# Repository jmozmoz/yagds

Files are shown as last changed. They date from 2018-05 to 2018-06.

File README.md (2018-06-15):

# yagds
This project is yet another garage door sensor.

Sensor data of changing door positions are captured by two reed sensors
connected to a ESP-01 module and
forwarded using the MQTT to a MQTT broker. A Python script subscribes to
these MQTT messages and implements a state machine representing the state of
the door (open, closed, moving). If the state of the door changes a Telegram
Bot notifies Telegram clients connected to it.

carrier board schematics

By using Telegram to distribute changes, the MQTT broker does not need to be
accessible from the internet. Also the Android Telegram Bot supports Android
Auto, so the garage door state can easily be sent to your car.

## Hardware

### ESP-01 module

The hardware is based on the ESP-01 module using the microchip
[ESP8266](https://en.wikipedia.org/wiki/ESP8266) microcontroller. This
microchip includes a micro controller with WIFI and TCP/IP capabilities and
can be programmed with the Arduino tool chain. The ESP-01 provides easy
access to 8 of the pins of the microchip of which up to 4 can be used as
general purpose input/output (GPIO): GPIO0, GPIO2, TX(GPIO1), RX(GPIO3)

But the voltage level of some of the GPIO pins are used to select the
[boot mode](https://github.com/esp8266/esp8266-wiki/wiki/Boot-Process#esp-boot-modes)
during power-up/after a reset. The configuration which finally worked for me,
is using GPIO0 and GPIO3 and make sure, that they are at high voltage
level (3.3 V) during reset.

### Carrier Board

The micro controller should go to deep sleep mode after the door reached the
open or closed position. This saves energy if the hardware should be powered
by battery. To wake-up it up again, changes at the reed contacts should
trigger a pulse on the RST pin. Based on the idea described
[here (in German)](http://esp8266-server.de/Reedkontakt.html) for both, GPIO0
and RX, a XOR gate is used to compare the signal with a delayed one. The latter
is produced by RC-circuits. If the signal changes, the delayed signal keeps is
different from the un-delayed signal and the XOR gate outputs one (the two
gates in the top left part of the schematics below). If at least one of
the signals has changed its state, the output of the OR gate is one.
The output of the OR gate is inverted by another XOR gate (top right of the
schematics) and used as input for the RST (reset) pin.

To make sure, that the GPIO pins are at high voltage to boot correctly the
output of the OR gate is delayed by another RC circuit and ORed with the
signals of the GPIO pins. So these pins stay at high until the boot-up
has been completed.

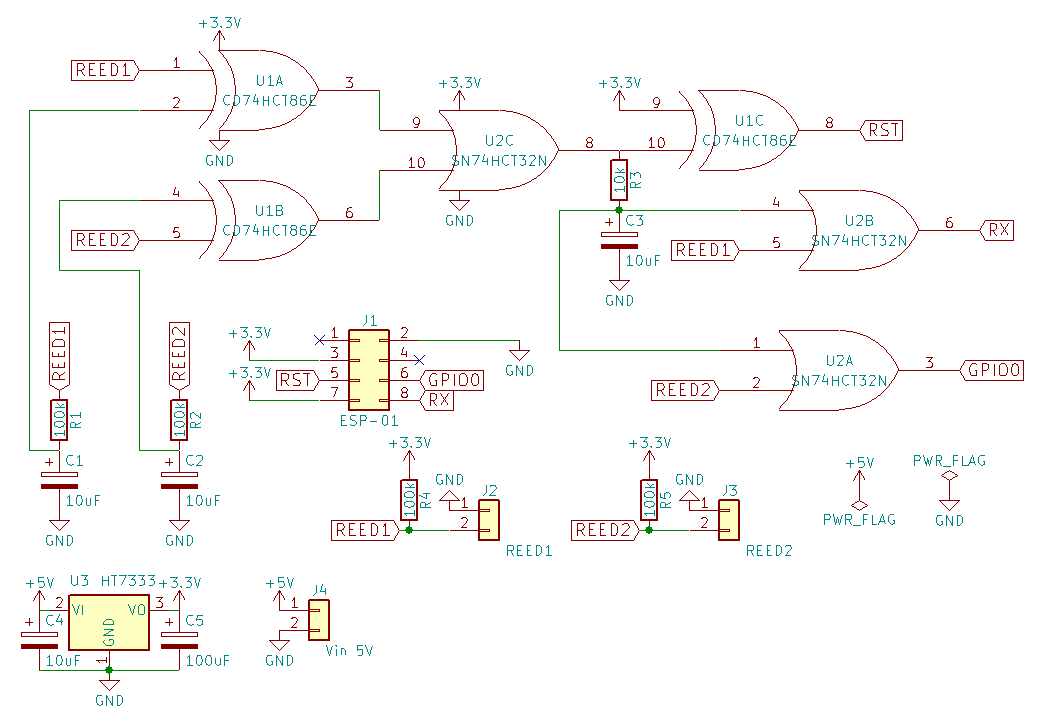
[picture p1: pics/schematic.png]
carrier board schematics


The RC circuits and the OR/XOR gates together with a voltage regulator
for the 3.3 V power supply of the gates and ESP-01 are combined on
a PCB board which carry the ESP-01.

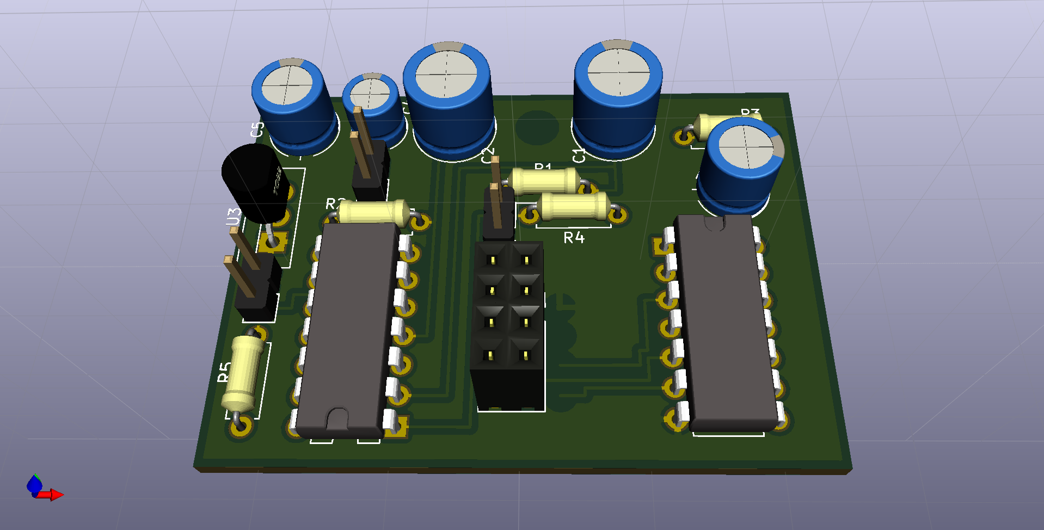
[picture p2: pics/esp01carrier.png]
carrier board 3d


The cables of the reed contacts are connected with RCA (cinch) connectors
to the carrier board. A micro USB socket is used for power supply.

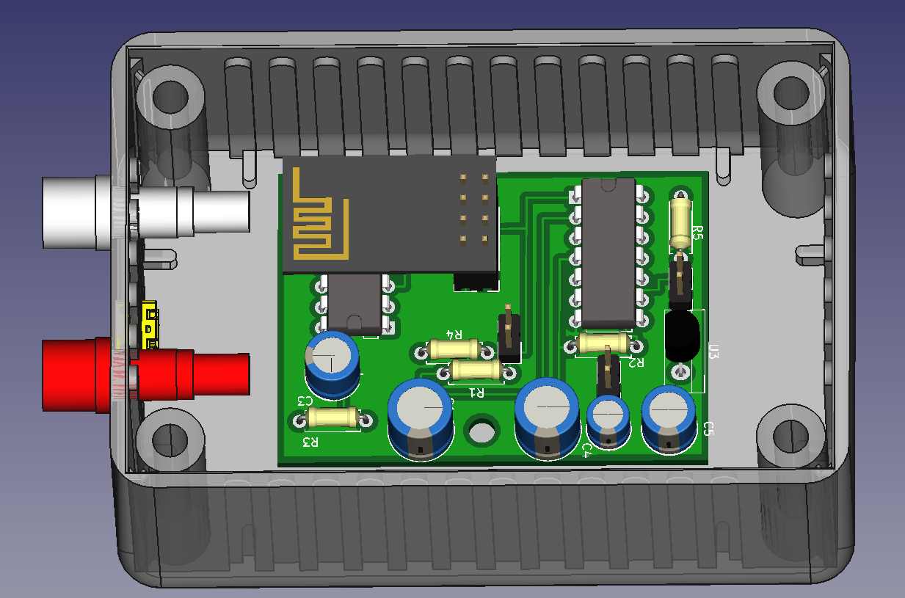
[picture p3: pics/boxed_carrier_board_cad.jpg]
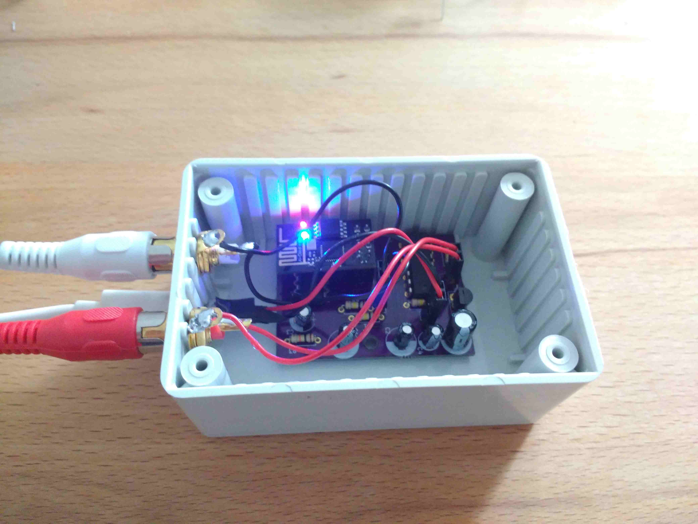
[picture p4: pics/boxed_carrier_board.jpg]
 

The schematics and PCB layout can be found in folder [layout_kicad](layout_kicad/).
They were created using [KiCad](http://kicad-pcb.org/)

## Software

### ESP-01 Firmware
The [firmware of the ESP-01](uploadSensorData/) is developed using
[PlatformIO](https://platformio.org/).

The communication with the MQTT
broker and the handling of configuration data (including updating them
over the air/the MQTT broker) is handled by the library
[Homie](https://github.com/marvinroger/homie-esp8266).

The library [simpleTimer](https://github.com/jfturcot/SimpleTimer) is
used to timeout connection setup and putting the micro  controller into
deep sleep state.

LED debug output flashing patterns are generated using the library
[jled](https://github.com/jandelgado/jled).

To set the configuration, add the file `data/homie/config.json` and
upload it the ESP-01 using Upload SPIFFS image.
```
{
  "name": "YAGDS",
  "device_id": "door_sensor",
  "device_stats_interval": 60,
  "wifi": {
    "ssid": "xxx",
    "password": "yyy"
  },
  "mqtt": {
    "host": "alpha",
    "port": 8883,
    "base_topic": "homie/",
    "auth": true,
    "username": "aaa",
    "password": "bbb",
    "ssl": true,
    "ssl_fingerprint": "123456789abcedf"
  },
  "ota": {
    "enabled": false
  },
  "settings": {
    "sensor_update_interval": 2,
    "max_resend": 5,
    "connection_timeout": 30,
    "sleep_timeout": 10
  }
}
```

Known issues: 
* My board is affected by this 
[bug](https://github.com/marvinroger/homie-esp8266/issues/522), 
which requires 
[patching](https://github.com/esp8266/Arduino/issues/4061#issuecomment-368273656) 
the ESP8266 core for Arduino.
* To use SSL fingerprints for the connection between the ESP-01
and a MQTT broker, a special build flag has to set: 
`build_flags = -DASYNC_TCP_SSL_ENABLED=1`. Also consider this
[issue](https://github.com/marvinroger/async-mqtt-client/issues/53).

### Telegram Bot with state machine
A [Python script](mqtt_telegram_bot/) determines the state of
the door and sends out messages if the state changes.
[paho-mqtt](https://pypi.org/project/paho-mqtt/) is used
to subscribe to the MQTT broker to receive the message from the ESP-01.
The transitions between different states of the door are followed
using the library
[transitions](https://pypi.org/project/transitions/). Message
of the current signal of the reed contacts can trigger changes between
the different door states as shown in the picture below.
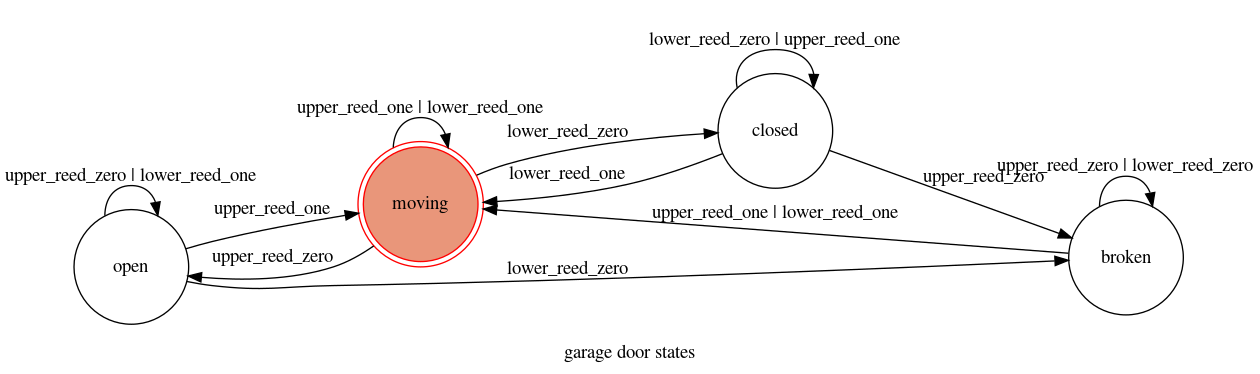
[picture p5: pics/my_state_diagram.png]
garage door states


If a transition causes a state change, also message is sent using the
[Python Telegram Bot](https://pypi.org/project/python-telegram-bot/)
library.

The `bot.py` scripts looks for the configuration file 
`.mqtt_telegram_bot.ini` in the $HOME directory of the user, or
for the file specified with the option `-c` at startup. It 
contains information about the connection to the MQTT broker and the
Telegram Bot.
```
[MQTT]
broker = broker.address
ca = ~/mqtt_ca.crt
username = username
password = password
topics_path = homie/door_sensor/reeds/#

[Telegram]
token = TOKEN
chat_id = 12345
```

## Authors

* **Joachim Herb** - [jmozmoz](https://github.com/jmozmoz)

## License

This project is licensed under [GPL v3](LICENSE)

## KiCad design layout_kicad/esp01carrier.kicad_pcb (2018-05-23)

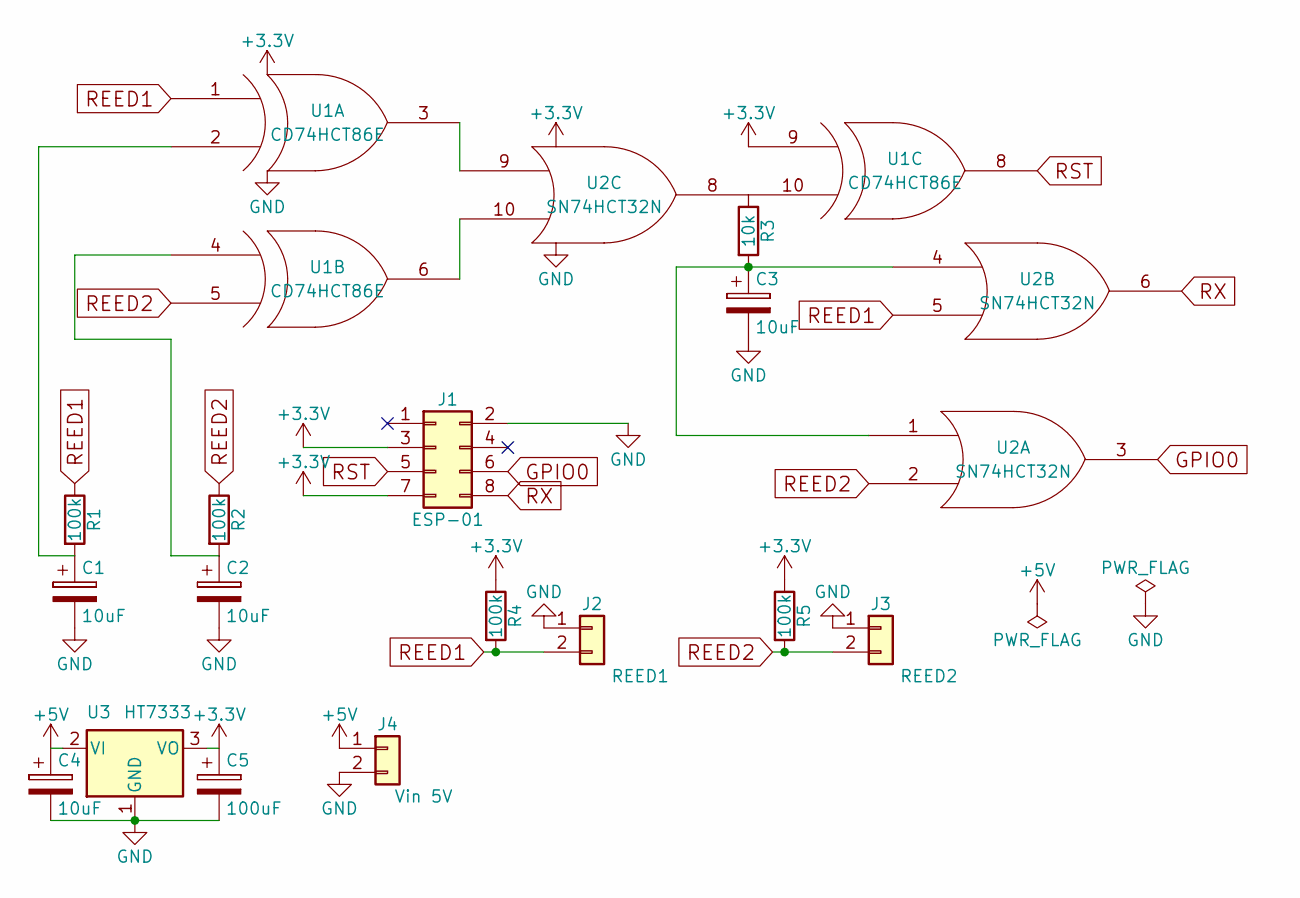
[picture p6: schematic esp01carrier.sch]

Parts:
C1, C2: 10uF; CP_Radial_D7.5mm_P2.50mm
C3: 10uF; CP_Radial_D6.3mm_P2.50mm
C4: 10uF; CP_Radial_D5.0mm_P2.50mm
C5: 100uF; CP_Radial_D6.3mm_P2.50mm
J1: ESP-01; Socket_Strip_Straight_2x04_Pitch2.54mm
J2: REED1; Pin_Header_Straight_1x02_Pitch2.54mm
J3: REED2; Pin_Header_Straight_1x02_Pitch2.54mm
J4: Vin 5V; Pin_Header_Straight_1x02_Pitch2.54mm
R1, R2, R4, R5: 100k; R_Axial_DIN0207_L6.3mm_D2.5mm_P7.62mm_Horizontal
R3: 10k; R_Axial_DIN0207_L6.3mm_D2.5mm_P7.62mm_Horizontal
U1: CD74HCT86E; DIP-14_W7.62mm
U2: SN74HCT32N; DIP-14_W7.62mm
U3: HT7333; TO-262_I2PAK_Vertical

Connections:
+3V3: C5.1, J1.3, J1.7, R4.1, R5.1, U1.9 (IN1), U1.14 (VCC), U2.14 (VCC), U3.3 (VO)
+5V: C4.1, J4.1, U3.2 (VI)
GND: C1.2, C2.2, C3.2, C4.2, C5.2, J1.2, J2.1, J3.1, J4.2, U1.7 (GND), U2.7 (GND), U3.1 (GND)
GPIO0: J1.6, U2.3
unnamed: C1.1, R1.2, U1.2 (IN2)
unnamed: C2.1, R2.2, U1.4 (IN1)
unnamed: C3.1, R3.2, U2.1, U2.4
unnamed: R3.1, U1.10 (IN2), U2.8
unnamed: U1.3 (OUT), U2.9
unnamed: U1.6 (OUT), U2.10
REED1: J2.2, R1.1, R4.2, U1.1 (IN1), U2.5
REED2: J3.2, R2.1, R5.2, U1.5 (IN2), U2.2
RST: J1.5, U1.8 (OUT)
RX: J1.8, U2.6

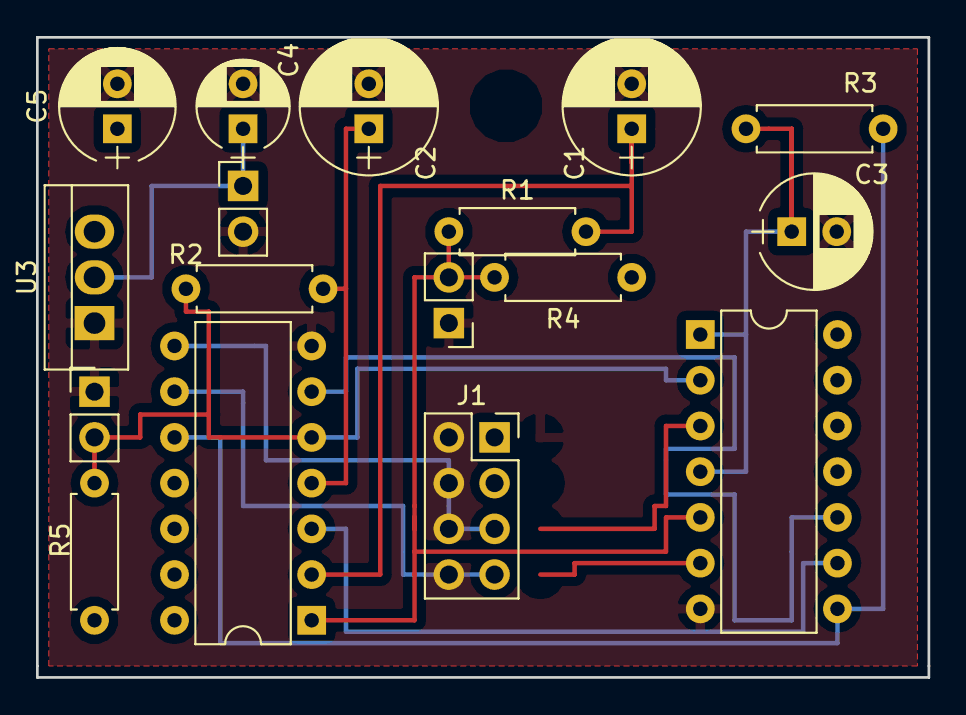
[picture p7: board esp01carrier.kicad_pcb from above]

Board: 2 copper layers, 49.5 x 35.6 mm, 17 parts (0 on the bottom side), 14 nets.

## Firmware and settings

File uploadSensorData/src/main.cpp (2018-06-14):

#include <Homie.h>
#include <SimpleTimer.h>
#include <ESP8266WiFi.h>

#include "debug_output.hpp"

#define MQTT_SERVER_FINGERPRINT {0xd6, 0x27, 0x18, 0xdd, 0x09, 0xce, 0x3d, 0x80, 0x1f, 0x59, 0x7a, 0x2b, 0x29, 0x78, 0x93, 0xe8, 0x0b, 0x82, 0x8a, 0x5d}

ADC_MODE(ADC_VCC);

const unsigned int upperReed = 0;     // GPIO0
const unsigned int lowerReed = 3;     // RX

const unsigned int DEFAULT_NUMBER_RESEND = 5;
int resendMessage = 0;

HomieSetting<long> sensor_update_interval("sensor_update_interval", "interval for sensor updates");
HomieSetting<long> connection_timeout("connection_timeout", "timeout for connection establishing");
HomieSetting<long> sleep_timeout("sleep_timeout", "timeout for going to sleep");
HomieSetting<long> maxResendMessage("max_resend", "number of times message are sent before going to sleep");

const unsigned int SENSOR_UPDATE_INTERVAL_DEFAULT = 2;
const unsigned int CONNECTION_TIMEOUT_DEFAULT = 30;
const unsigned int SLEEP_TIMEOUT_DEFAULT = 10;
const bool DEBUG_SERIAL_OUTPUT = false;

int publishTimerId;
int connectionTimeoutId;
int sleepTimeoutId;

HomieNode reedNode("reeds", "state");
HomieNode vccNode("powerSupply", "voltage");

SimpleTimer homieLoopTimer;
SimpleTimer mainLoopTimer;

DebugOutput debugOutput;

void gotoDeepSleep() {
    Homie.getLogger() << F("Really goto sleep") << endl;   
    Homie.doDeepSleep(0UL, RF_DEFAULT);
    ESP.deepSleep(0UL, RF_DEFAULT);
}

void checkGotoSleep(int upperReedState, int lowerReedState) {
  if ((!upperReedState || !lowerReedState) &&
      (Homie.getMqttClient().connected()) &&
      (++resendMessage >= maxResendMessage.get())) {
    homieLoopTimer.deleteTimer(publishTimerId);
    sleepTimeoutId = mainLoopTimer.setTimeout(sleep_timeout.get() * 1000UL, gotoDeepSleep);
    debugOutput.checkGotoSleep();
    Homie.prepareToSleep();
  }
}

void publishStates() {
  int upperReedState = digitalRead(upperReed);
  int lowerReedState = digitalRead(lowerReed);
  uint16_t voltage = ESP.getVcc();
  
  Homie.getLogger() << F("Upper reed: ") << upperReedState << endl;
  Homie.getLogger() << F("Lower reed: ") << lowerReedState << endl;
  Homie.getLogger() << F("Voltage: ") << voltage << endl;

  reedNode.setProperty("upperReed").send(String(upperReedState));
  reedNode.setProperty("lowerReed").send(String(lowerReedState));
  vccNode.setProperty("voltage").send(String(voltage));

  checkGotoSleep(upperReedState, lowerReedState);
}

void loopHandler() {
  homieLoopTimer.run();
}

void onHomieEvent(const HomieEvent& event) {
  switch(event.type) {
    case HomieEventType::MQTT_READY:
      mainLoopTimer.disable(connectionTimeoutId);
      debugOutput.mqtt_ready();
      break;
    case HomieEventType::MQTT_DISCONNECTED:
      mainLoopTimer.restartTimer(connectionTimeoutId);
      mainLoopTimer.enable(connectionTimeoutId);
      break;
    case HomieEventType::READY_TO_SLEEP:
      Homie.getLogger() << F("Ready to sleep") << endl;
      mainLoopTimer.setTimeout(0, gotoDeepSleep);
      break;
    default:
      break;
  }
}

void connectionTimedOut() {
  debugOutput.connectionTimedOut();
  Homie.prepareToSleep();
}

void setup() {
  debugOutput.enable_serial(DEBUG_SERIAL_OUTPUT);

  Homie.disableResetTrigger();  // we do not want to trigger config mode by sensor input

  pinMode(upperReed, INPUT);
  pinMode(lowerReed, INPUT_PULLUP);
  
  Homie_setFirmware("uploadSensorData", "1.0.0"); // The underscore is not a typo! See Magic bytes

  Homie.setLoopFunction(loopHandler);
  Homie.onEvent(onHomieEvent);

  sensor_update_interval.setDefaultValue(SENSOR_UPDATE_INTERVAL_DEFAULT);
  connection_timeout.setDefaultValue(CONNECTION_TIMEOUT_DEFAULT);
  sleep_timeout.setDefaultValue(SLEEP_TIMEOUT_DEFAULT);
  maxResendMessage.setDefaultValue(DEFAULT_NUMBER_RESEND);
  
  WiFi.setPhyMode(WIFI_PHY_MODE_11N);
  WiFi.setOutputPower(20.5);

  Homie.setup();

  publishTimerId = homieLoopTimer.setInterval(sensor_update_interval.get() * 1000UL, publishStates);
  connectionTimeoutId = mainLoopTimer.setTimeout(connection_timeout.get() * 1000UL, connectionTimedOut);

#if ASYNC_TCP_SSL_ENABLED
  Homie.getLogger() << endl << endl << F("ESP Homie Using TLS") << endl;
  Homie.getMqttClient().setSecure(true);
  Homie.getMqttClient().addServerFingerprint((const uint8_t[])MQTT_SERVER_FINGERPRINT);
#endif
  Homie.getLogger() << endl << endl << F("setup finished") << endl;  
}

void loop() {
  debugOutput.update();
  if (homieLoopTimer.getNumTimers()) {
      Homie.loop();
  }
  mainLoopTimer.run();
}

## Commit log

2018-05-06 Add kicad project
    [esp01carrier.kicad_pcb, esp01carrier.sch]
2018-05-23 Add LED state signaling (alternative to serial output)
2018-05-23 Change RC-curcuits to reduce current
    [esp01carrier.kicad_pcb, esp01carrier.sch]
2018-05-26 class for debug output (LED/serial), force maximal Wifi power
